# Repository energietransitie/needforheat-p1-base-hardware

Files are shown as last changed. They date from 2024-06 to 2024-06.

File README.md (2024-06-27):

# NeedForHeat P1-BASE hardware <!-- omit in toc -->

This repository contains the open hardware design files for the NeedForHeat P1-BASE device, which can be used as a [CoreInk BASE extension module](https://docs.m5stack.com/en/coreink/proto_base), on the back of an [M5Stack CoreInk](https://docs.m5stack.com/en/core/coreink) device. 

The NeedForHeat P1-BASE enables reading [smart meters that adhere to the Dutch Smart Meter Requirements](https://github.com/energietransitie/dsmr-info) via the [P1 port](https://nl.wikipedia.org/wiki/P1-poort).

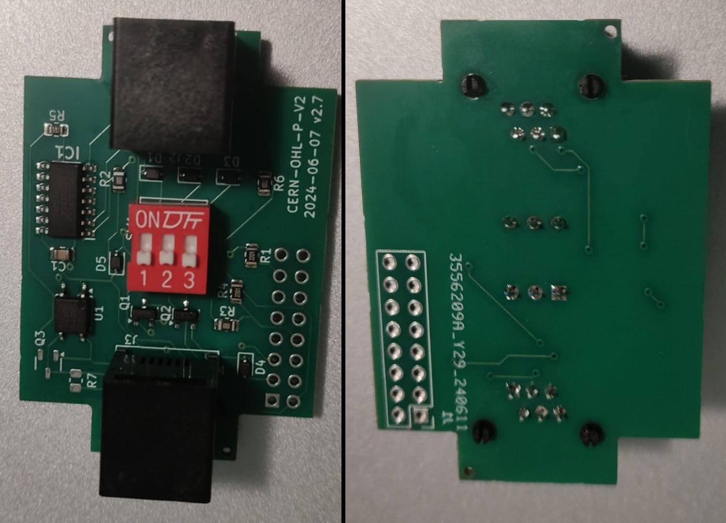
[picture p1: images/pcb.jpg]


## Table of contents <!-- omit in toc -->
- [General info](#general-info)
- [Producing](#producing)
  - [Printed Circuit Board](#printed-circuit-board)
  - [Enclosure](#enclosure)
- [Deploying](#deploying)
  - [Cost](#cost)
  - [Connecting](#connecting)
  - [Setting the DIP Switches](#setting-the-dip-switches)
- [Developing](#developing)
  - [Printed Circuit Board](#printed-circuit-board-1)
- [Features](#features)
- [Status](#status)
- [License](#license)
- [Credits](#credits)

## General info
This repository contains the open hardware designs files for the NeedForHeat P1-BASE. It also includes a `docs` folder with recent printouts of the [schematics](./docs/needforheat-p1-base-hardware-sch.pdf) and [PCB layout](./docs/needforheat-p1-base-hardware-pcb.pdf). 

For the associated firmware that you can run on this device, please see [this repository](https://github.com/energietransitie/needforheat-p1-reader-firmware).

## Producing

### Printed Circuit Board
To manufacture the printed circuit board you can use various PCB services. 

The folder [pcb/jlcpcb](./pcb/jlcpcb) includes all exported files needed to have the PCBs manufactured by [JLCPCB](https://www.jlcpcb.com). Upload the [zipped gerber files](./pcb/jlcpcb/assembly/GERBER-needforheat-p1-base-hardware.zip) to the [JLCPCB quote page](https://cart.jlcpcb.com/quote), select the amount of PCBs and a colour for the silkscreen. All other options can be left on default. 

If you do not want to solder components on the PCB yourself, select `PCB assembly` and JLCPCB will do it for you (even for through-hole components if you so desire). This will take you to a page where the BOM and POS file can be uploaded. Use the files [BOM-needforheat-p1-base-hardware.csv](./pcb/jlcpcb/assembly/BOM-needforheat-p1-base-hardware.csv) and [CPL-needforheat-p1-base-hardware.csv](./pcb/jlcpcb/assembly/CPL-needforheat-p1-base-hardware.csv).

JLCPCB provides detailed steps on their website to select component assembly, including wave soldering. For wave soldering or through-hole component assembly, specify this requirement when uploading your BOM and POS files. 

> After uploading BOM and CPL, you may be asked to select a component for `Q3`. You do not need to do so and can select 'do not place'. For more information, see the [design document](docs/documentation.md#optional-components).

### Enclosure

An enclosure for this device has not been developed yet.

<!-- an enclosure has not been developed yet
To fabricate the enclosure you can use your own 3D printer or use a 3D printing service. 

<img src="./images/enclosure.jpg" height="600" />

The folder [enclosure/fabrication](./enclosure/fabrication) contains exported STL files for the [case](./enclosure/fabrication/twomes-hardware-repository-template-case.stl) and [lid](./enclosure/twomes-hardware-repository-template-lid.step) of the NeedForHeat P1-BASE enclosure. The STL files can be imported into any slicer and turned into G-Code for a 3D printer.
-->

## Deploying

To deploy P1-BASE to a home as the NeedForHeat Smart Meter module, in addition to the PCB you need additional hardware: enclusure, M5Stack CoreInk, a short RJ12 cable and for some homes a power adapter. In this section we describe the cose and connections.

### Cost

Prices indicate price per module in June 2024, based on ordering enough hardware for 10 modules, including 21% VAT and shipping to an address in the Netherlands.

| # | Item | Supplier | Price per Unit | Subtotal |  Shipping | Total |
| --- | --- | --- | ---: | ---: | ---: | ---: |
| 1 | P1-BASE PCB | JLCPCB | €2.40 | €2.40 | €2.38 | €4.78 |
| 1 | P1-BASE enclosure | JLCPCB | €1,30 | €1,30 | €2,40 | €3,60 |
| 1 | [M5Stack CoreInk](https://www.tinytronics.nl/nl/platformen-en-systemen/m5stack/e-paper/m5stack-m5core-ink-met-1.54-inch-e-paper-e-ink-display-esp32) | TinyTronics | €43.00 | €43.00 | €0.00 | €43.00 |
| 4 | [LEGO pen stroef + pen stroef](https://www.blokjeskoning.nl/product/pen-stroef-pen-stroef-zwart/) | Blokjeskoning | €0.03 | €0.12 | €0.30 | €0.42 |
| 1 | [RJ12 cable (male-male; 6P6C; straight; 0.5 m or shorter)](https://www.amazon.nl/-/en/InLine-18848A-Modular-Cable-6-Core/dp/B005I1UDOE/)[^1] | AlleKabels  | €5.95 | €5.95 | €0.00 | €5.95 |
| 1 | [USB-A 230V charger + USB-A to USB-C cable](https://www.allekabels.nl/usb-oplader/4508/3636716/usb-a-oplader-usb-c-kabel.html) | AlleKabels  | €14.95 | €14.95 | €0.13 | €15.08 |
| | **TOTAL** | | **€67.60** | **€67.72** | **€6,21** | **€72,83** |

[^1]: The shorter the cable the better: this allows users to simply click in the RJ12 connector of te to the P1 port of their smart to leave and leave the NeedForHeat smart meter reader device dangling from the P1-port;*

### Connecting

Assuming that the PCB is fully assembled, the device has an enclosure, and the device has been programmed with the [needforheat-p1-reader-firmware](https://github.com/energietransitie/needforheat-p1-reader-firmware), you can proceed and connect the device as follows:

Before sending the device to a home:

1. Mount the P1-BASE in its enclosure.
1. Connect the short RJ12 cable to the upper female RJ12 connector[^2].
1. Insert 2 lego pens in the enclusure at opposite diagonal corners. 
1. Insert 2 lego pens in the holes on the back side of the M5Stack CoreInk at opposite diagonal corners.
4. Do NOT connect the P1_BASE and M5Stack CoreInk, before sending, since they will not fit in a standard [PostNL brievenbusdoos](https://shop.postnl.nl/webshop/verpakkingen/brievenbusdoos-a5-255x160x28mm) when stacked.

[^2]: By pre-connecting the RJ12 cable to connector `J2` on the PCB, you help users at home avoid installation errors. You may even consider clipping off 3 to 4 mm from the latch of the modular conector. After insertion the connector does not protrude from the female connecto, which clearly signals to the user that this cable should not be deinstalled. 

After receiving the device in a home:
1. Connect to the P1-BASE to the based of the M5Stack CoreInk, ensuring alignment of M5Stack CoreInk with the P1-BASE; the LEGO pins will help make sure that the 2x8 pin connector of the P1-BASE properly connects to M5Stack CoreInk.
2. Unplug your existing smart meter reader (if any) from the P1 port smart meter
3. Connect the plug of the NeedForHeat smart meter module in the P1 port .
4. Plug the RJ16 connector of our existing smart meter reader into the bottom RJ12 socket of the P1-BASE.

### Setting the DIP Switches

The hardware version v2.7 (2024-06-07) features 3 DIP switches on the PCB to control data request line management. Adjust the switches according to the following settings before delivering the device to the user:

| DIP-switch Number | ON Position | OFF Position |
| --- | --- | --- |
| 1 | Data requested continuously (DSMR 4 & 5) | Data not requested continuously |
| 2 | Data request driven by M5Stack CoreInk | Data request from M5Stack CoreInk ignored |
| 3 | Data request driven by external smart meter reader | Data request from external smart meter reader ignored |

If multiple DIP switches are ON simultaneously, data is requested if any corresponding source requires it. This may cause the external smart meter reader to receive partial messages, but according to the [DSMR P1 Port Companion Standard](https://github.com/energietransitie/dsmr-info?tab=readme-ov-file#dsmr-versions-standards) since version 3.0, smart meter readers should be able to handle partial messages.

## Developing

### Printed Circuit Board
To change the hardware design of the PCB, you need:
* [KiCad version 8.0.0 or later](https://www.kicad.org/download/) installed to change te PCB design. 

The KiCad source files of the PCB can be found in the folder [pcb](./pcb).

To convert the PCBs into a format suitable for fabrication, consult the webpage of your PCB manufacturer of choice. For example, see the [JLCPCB guide on how to export Gerbers](https://support.jlcpcb.com/article/149-how-to-generate-gerber-and-drill-files-in-kicad) and the  [JLCPCB guide how to export the BOM and POS files](https://support.jlcpcb.com/article/84-how-to-generate-the-bom-and-centroid-file-from-kicad). You may also use a KiCad plug-in for this purpose such as [kicad-jlcpcb-tools](https://github.com/Bouni/kicad-jlcpcb-tools).

<!-- 
### Enclosure
To change the hardware design of the enclosure, you need either:
* [Autodesk Fusion 360](https://www.kicad.org/download/) installed (Autodesk provides 30 day free trials and [free one-year educational access](https://www.autodesk.com/education/edu-software/overview?sorting=featured&filters=individual) to its products and services for eligible students, teachers and research staff); 
* or [FreeCAD](https://www.freecadweb.org/), an open source alternative.

The source files of the enclosure can be found in the folder [enclosure](./enclosure). We include both .f3d source files and .step source files we obtained after conversion.
-->

## Features

The NeedForHeat P1-BASE includes the following main hardware components:

- [x] Built-in P1-splitter for connecting an additional smart meter reader to the lower female RJ12 connector (`J3`).
- [x] Integrated [Schmitt trigger](https://en.wikipedia.org/wiki/Schmitt_trigger) to reduce signal noise.
- [x] 3 DIP-switches on the PCB for enabling/disabling data request line management.
- [x] Bottom-side 2x8 pin header for MI-BUS connection to the [M5Stack CoreInk](https://docs.m5stack.com/en/core/coreink) (requires soldering yourself, or a hefty JLCPCB fee for bottom-side hand-soldering).

To-do:

- [ ] Test compatibility with Landis+Gyr E360 series smart meters (e.g., [Landis+Gyr CD2D](https://www.landisgyr.eu/), [CM3D](https://www.landisgyr.eu/)).
- [ ] Consider using 'upside-down' RJ12 female connectors for easier [M5Stack CoreInk](https://docs.m5stack.com/en/core/coreink) screen readability.
- [ ] Evaluate relocating and optimizing the 2x8 pin header from the bottom side to the top side of the PCB to reduce manufacturing costs. 
  > (This would also obviate the need for 'upside-down' RJ12 female connectors, above.)
- [ ] Refine PCB design to reduce clutter where possible.
- [ ] Experiment with alternative data request management methods (e.g., MOSFETs, BJTs), which would allow the [M5Stack CoreInk](https://docs.m5stack.com/en/core/coreink) to check and control data request management in software.
- [ ] Implement low-power LEDs for indicating power status, data request status, and data flow.
- [ ] Develop energy-efficient charging strategies for the [M5Stack CoreInk](https://docs.m5stack.com/en/core/coreink) 390 mAh LiPo battery from DSMR 4 and DSMR 5 smart meters, without triggering the fold-back current limiting feature of some smart meters.
- [ ] Design a 3D-printable enclosure compatible with the [M5Stack CoreInk](https://docs.m5stack.com/en/core/coreink), potentially using [LEGO connector pens](https://www.blokjeskoning.nl/product/pen-stroef-pen-stroef-zwart/). A preliminary version can be found in the [needforheat-boiler-monitor-hardware repository](https://github.com/energietransitie/needforheat-boiler-monitor-hardware).

## Status
Project is:  _in progress_

## License
The hardware designs in this repository are available under the [CERN-OHL-P v2 license](./LICENSE), Copyright 2024 [Research group Energy Transition, Windesheim University of Applied Sciences](https://windesheim.nl/energietransitie)

## Credits
This open hardware design is a collaborative effort of:
* Rick de Graaf · [@277r](https://github.com/277r) 
* Gerwin ten Have · [@GerwintenHave](https://github.com/GerwintenHave) 

Product owners:
* Henri ter Hofte · [@henriterhofte](https://github.com/henriterhofte) · Twitter [@HeNRGi](https://twitter.com/HeNRGi)
* Marco Winkelman · [@MarcoW71](https://github.com/MarcoW71)

We use and gratefully acknowlegde the efforts of the makers of:
* [Twomes P1 Gateway Hardware](https://github.com/energietransitie/twomes-p1-gateway-hardware), by Research group Energy Transition at Windesheim University of Applied Sciences, licenced under Apache 2.0
* [KiCad Libraries](https://kicad.github.io/), by the KiCad Development Team, licensed under [an adapted version of the CC-BY-SA 4.0 License](https://www.kicad.org/libraries/license/)

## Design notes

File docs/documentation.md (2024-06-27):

# P1-BASE-hardware Documentation <!-- omit in toc -->

## Table of contents <!-- omit in toc -->
- [Usage](#usage)
- [Design choices](#design-choices)
  - [Smart meter connection](#smart-meter-connection)
  - [Data Request Line Management](#data-request-line-management)
  - [Internal Splitter](#internal-splitter)
  - [Optional components](#optional-components)

## Usage


> This guide assumes that the PCB's are fully assembled, that the device has an enclosure and that the device has been programmed with the [needforheat-p1-reader-firmware](https://github.com/energietransitie/needforheat-p1-reader-firmware) 

* The 2x8 male pin header (`J1`) soldered to the bottom side of the PCB should be connected to the M5Stack CoreInk. Of the two possible orientations, use the  one with the best alignment of the outline of the P1-BASE PCB with the outline M5Stack CoreInk. 
* The upper female RJ12 connector (`J2`) should be connector via a (preferably short) 6P6C male-to make stright RJ12 cable to the P1 port of the smart meter. 
* The lower female RJ12 connector (`J3`) allows another smart meter reading device to be connected via a straight RJ12 cable.

Once these connections have been made, the user can open the NeedForHeat application on their phone and scan a QR code from the E-Ink screen of the M5Stack CoreInk. 

## Design choices

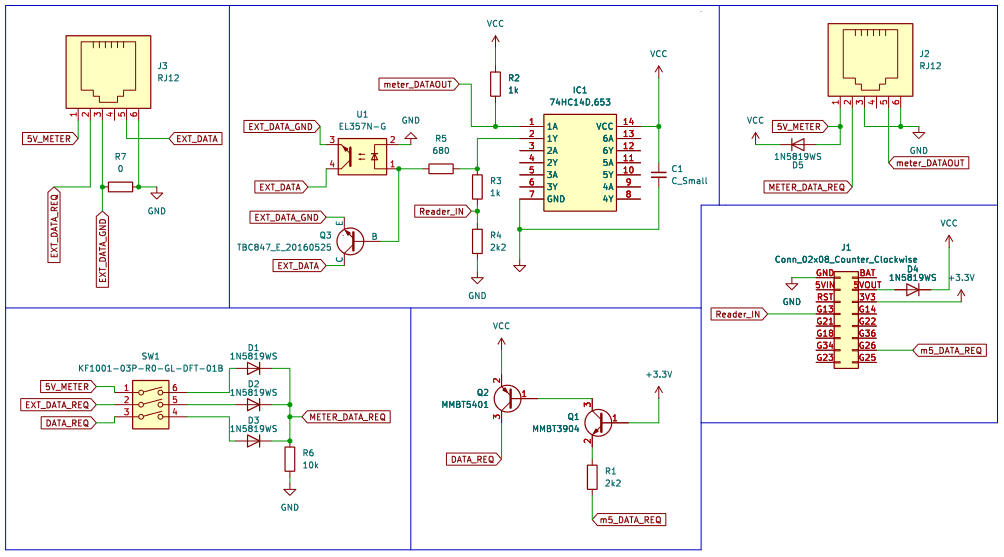
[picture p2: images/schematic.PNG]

The P1-BASE-hardware design was made as an improvement to the [twomes-p1-gateway-hardware](https://github.com/energietransitie/twomes-p1-gateway-hardware): 
* The hardware was developed to work on the M5Stack CoreInk instead of a bare ESP32.
* The [twomes-p1-gateway-hardware](https://github.com/energietransitie/twomes-p1-gateway-hardware) did not read P1 signals reliably from Landis+Gyr E360 series smart meters, such as the Landis+Gyr CD2D (meter code E0051) and CM3D (meter codes E0052 and E0067). The hardware design was also changed to address this problem and work on more smart meters.
* To allow  users who already have a smart meter reader connected to their smart meter, we added an internal P1 splitter to the design, which allows the user connect their smart meter reader to the bottom connector .

### Smart meter connection
The smart meter should be connected to upper female RJ12 connector (`J2`). A table of connections, referring to the official P1 port pin assignment can be seen below:

| Pin # | `J2` signal name | P1 Signal Name | P1 Description | P1 Remark |
| ----- | --- | --- | --- | --- |
| 1 | `5V_METER` | +5V | +5V power supply | Power supply line |
| 2 | `METER_DATA_REQUEST` | Data Request | Data Request Input | |
| 3 | `GND` | Data GND | Data ground | |
| 4 | | n.c. | Not connected | |
| 5 | `meter_DATAOUT` | Data | Data line | Output, Open collector |
| 6 | `GND` | Power GND | Power ground | Power supply line |

### Data Request Line Management
When the `Data Request` voltage (pin 2 on the female RJ12 connecor of the P1 port of the smart meter) is at `Data GND`+5V, the smart meter sends data.

The [twomes-p1-gateway-hardware/](https://github.com/energietransitie/twomes-p1-gateway-hardware/) design originally utilized a 10kΩ resistor and a 3.3V source, resulting in a high RC time constant and unreliable data reading. To address this, the design has been revised with a 1kΩ resistor and a 5V source, allowing for 5mA current flow and significantly improving signal integrity. The `meter_DATAOUT` signal is connected to a Schmitt-trigger (`IC1`) to enhance noise immunity. Transistors `Q1` and `Q2` are configured in a level-shifter circuit, converting the 3.3V logic signal (`m5_DATAREQ`) arriving from the M5Stack CoreInk via `G26` to a 5V logic signal (`DATA_REQ`), which is expected as `Data Request` input by the smart meter's P1-port.

### Internal Splitter

The internal splitter eliminates the need for external pre-wired components, simplifying user connections. It facilitates the addition of another smart meter reader without affecting the primary device's data request capabilities. Diodes are incorporated to prevent current flow to `GND` and ensure uninterrupted data request functionality. 

A DIP switch (`SW1`) enables configuration of `5V_METER`, `EXT_DATA_REQ`, and `DATA_REQ` signals to `METER_DATA_REQ`, linked via `J2` to the smart meter's data request line. For setup details, refer to the [DIP switch configuration section in the main README](../README.md#setting-the-dip-switches), which explains how these settings influence operational behavior.

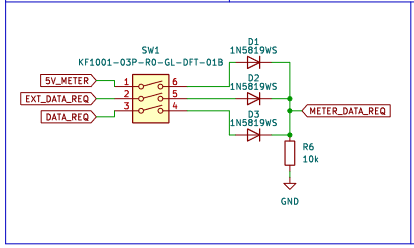
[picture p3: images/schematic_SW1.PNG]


### Optional components
* **Solder pads for `R7` and `Q3` are included on the PCB but not populated.** These components are provided for flexibility in adjusting the circuit's performance. They can be soldered if needed to enhance signal readout quality, particularly if the optocoupler (`U1`) proves insufficiently fast for the signals.

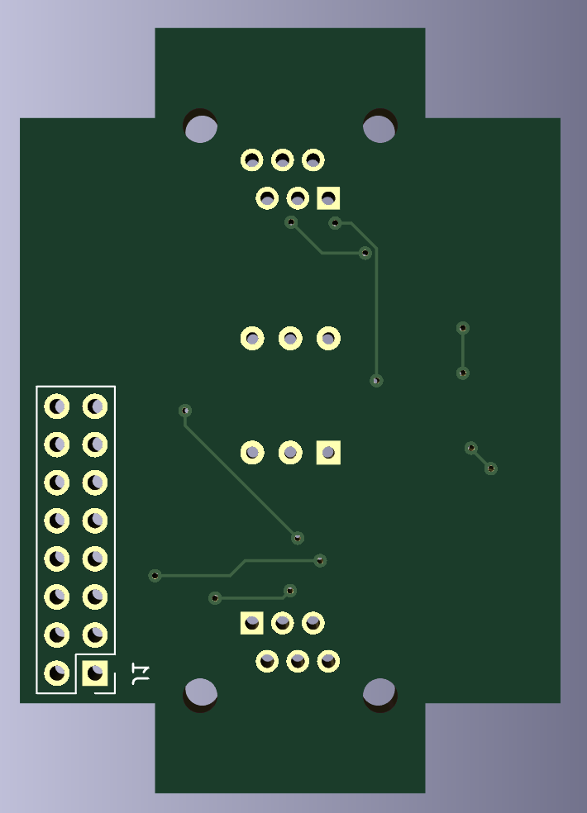
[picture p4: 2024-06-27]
images/needforheat-p1-base-hardware-bottom.PNG

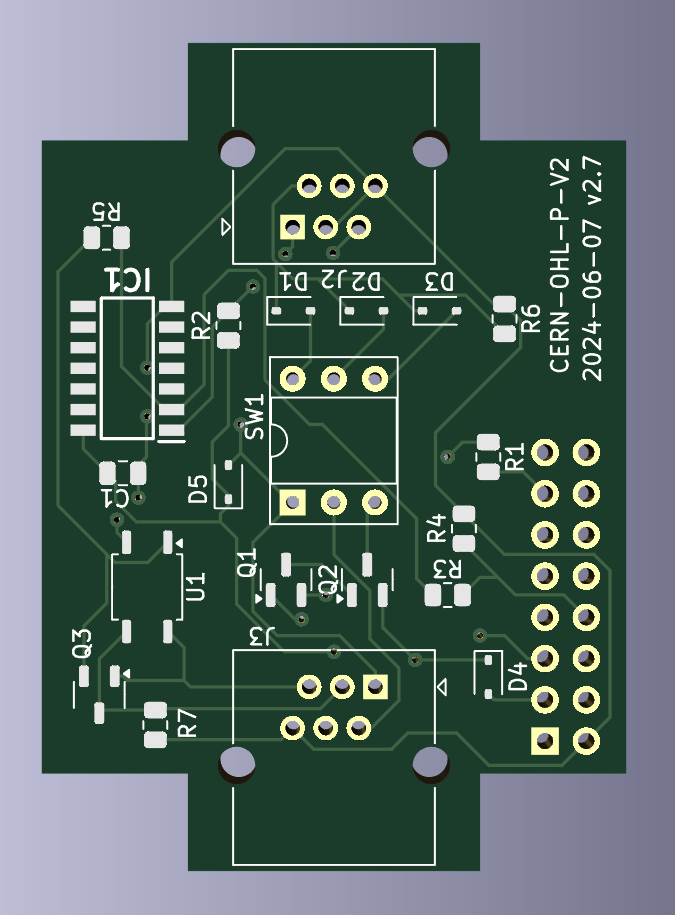
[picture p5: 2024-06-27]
images/needforheat-p1-base-hardware-top.PNG

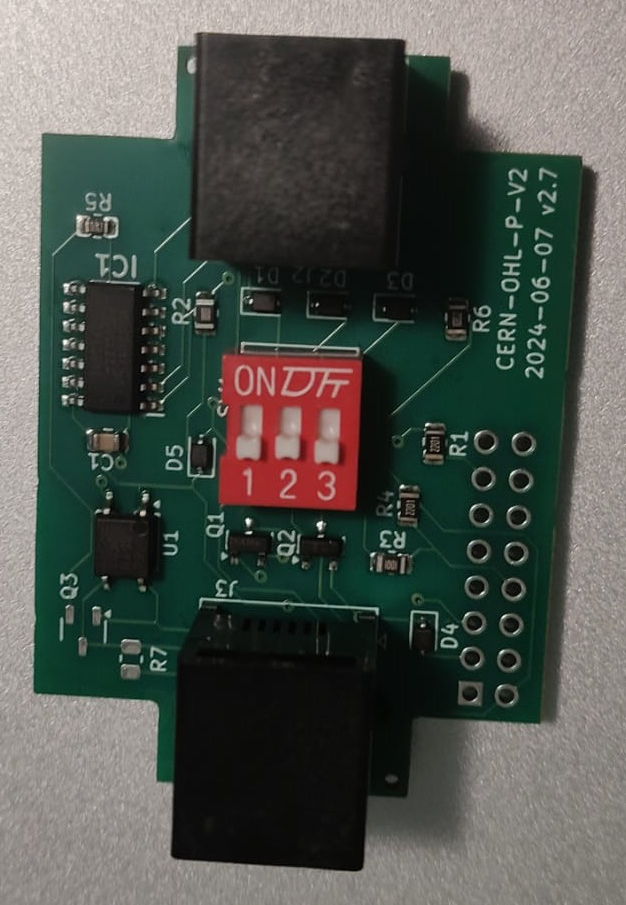
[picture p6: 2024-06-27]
images/front.jpg

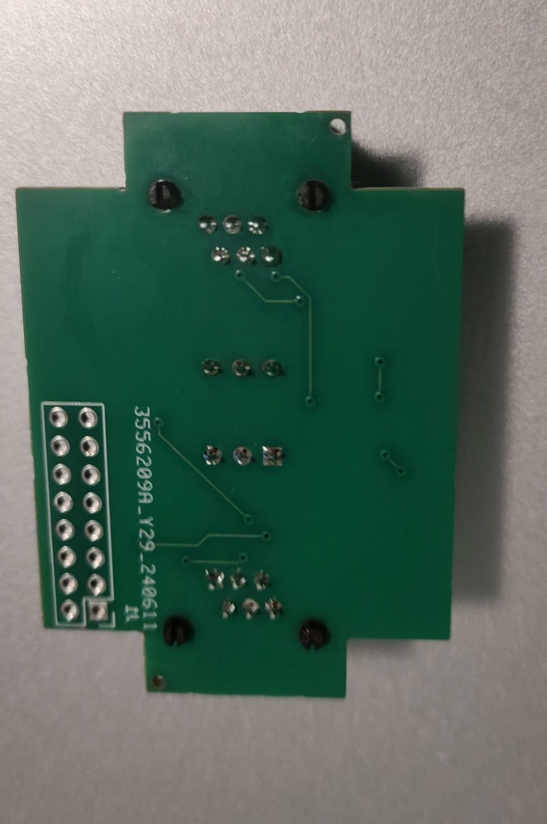
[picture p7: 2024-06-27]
images/back.jpg

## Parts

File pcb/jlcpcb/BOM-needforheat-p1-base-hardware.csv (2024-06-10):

Comment | Designator | Footprint | LCSC
10k | R6 | R_0805_2012Metric | C17414
1k | R2,R3 | R_0805_2012Metric | C17513
2k2 | R1,R4 | R_0805_2012Metric | C17520
1N5819WS | D1,D2,D3,D4,D5 | D_SOD-323 | C191023
MMBT3904 | Q1 | SOT-23 | C20526
680 | R5 | R_0805_2012Metric | C23228
EL357N-G | U1 | SOP-4_3.8x4.1mm_P2.54mm | C29981
C_Small | C1 | C_0805_2012Metric | C49678
74HC14D,653 | IC1 | SOIC127P600X175-14N | C5605
Conn_02x08_Counter_Clockwise | J1 | PinHeader_2x08_P2.54mm_Vertical | C68234
RJ12 | J2,J3 | RJ25_Wayconn_MJEA-660X1_Horizontal | C77859
MMBT5401 | Q2 | SOT-23 | C8326
KF1001-03P-R0-GL-DFT-01B | SW1 | DIP-6_W7.62mm_Socket | C976325
TBC847_E_20160525 | Q3 | SOT-23-3

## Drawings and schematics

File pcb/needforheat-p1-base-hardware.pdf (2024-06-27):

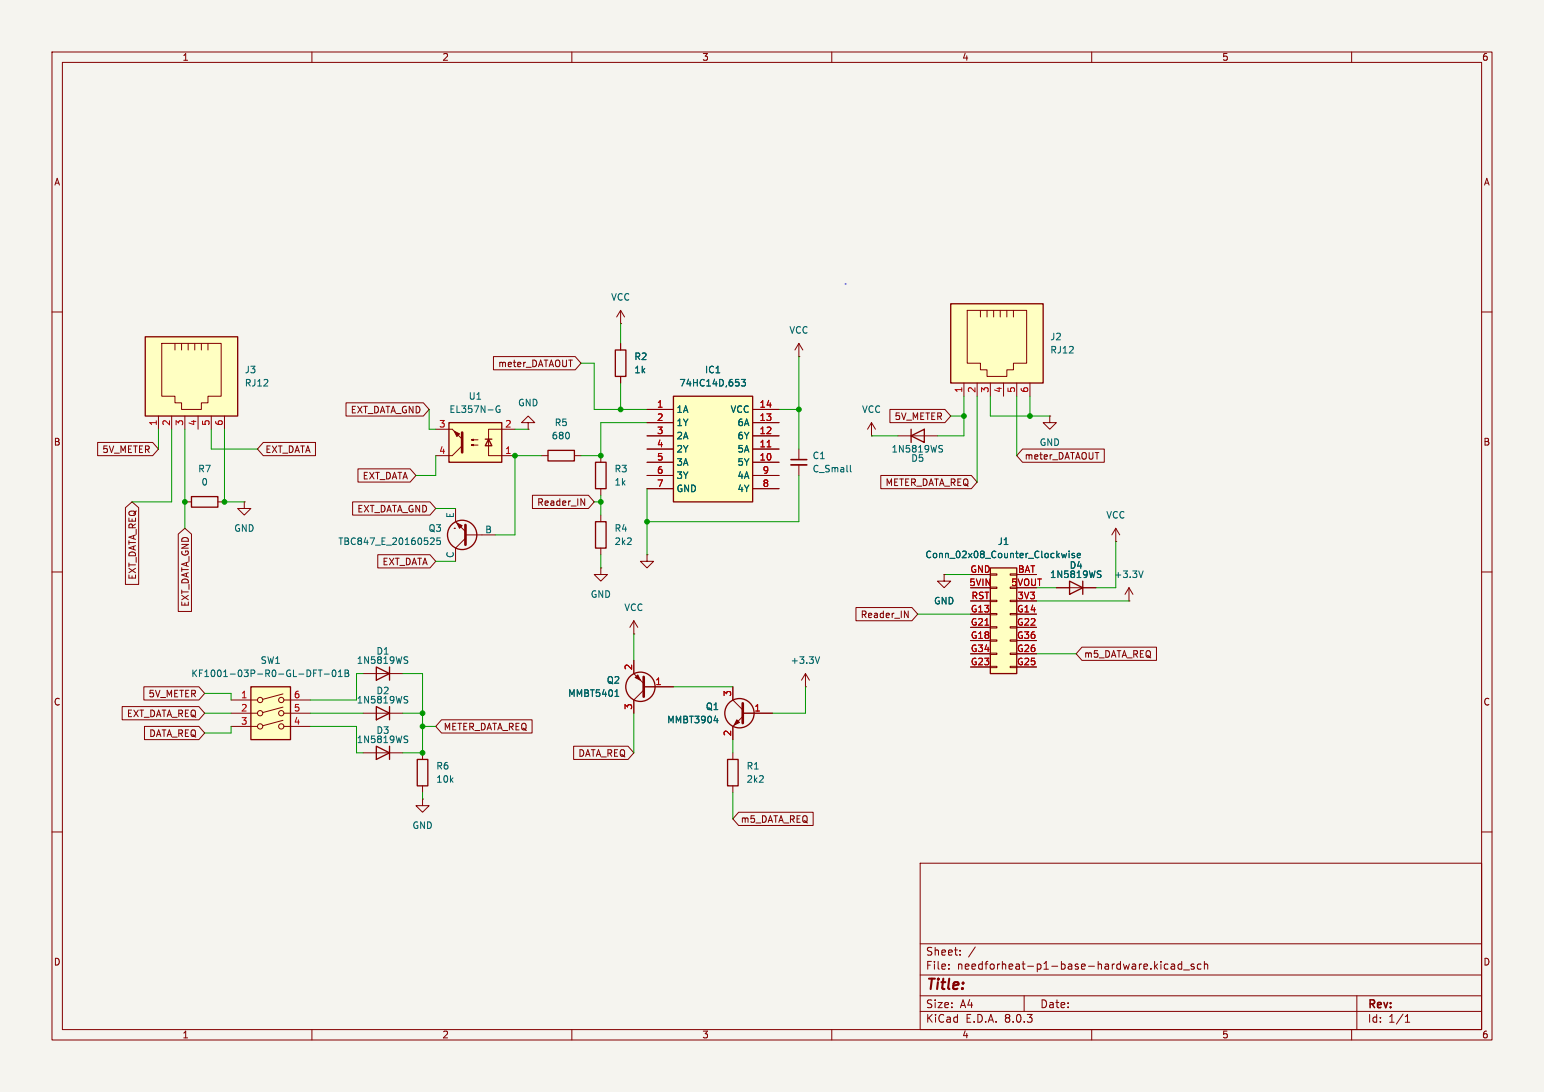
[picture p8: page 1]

Id: 1/1 Title: File: needforheat-p1-base-hardware.kicad_sch Sheet: /

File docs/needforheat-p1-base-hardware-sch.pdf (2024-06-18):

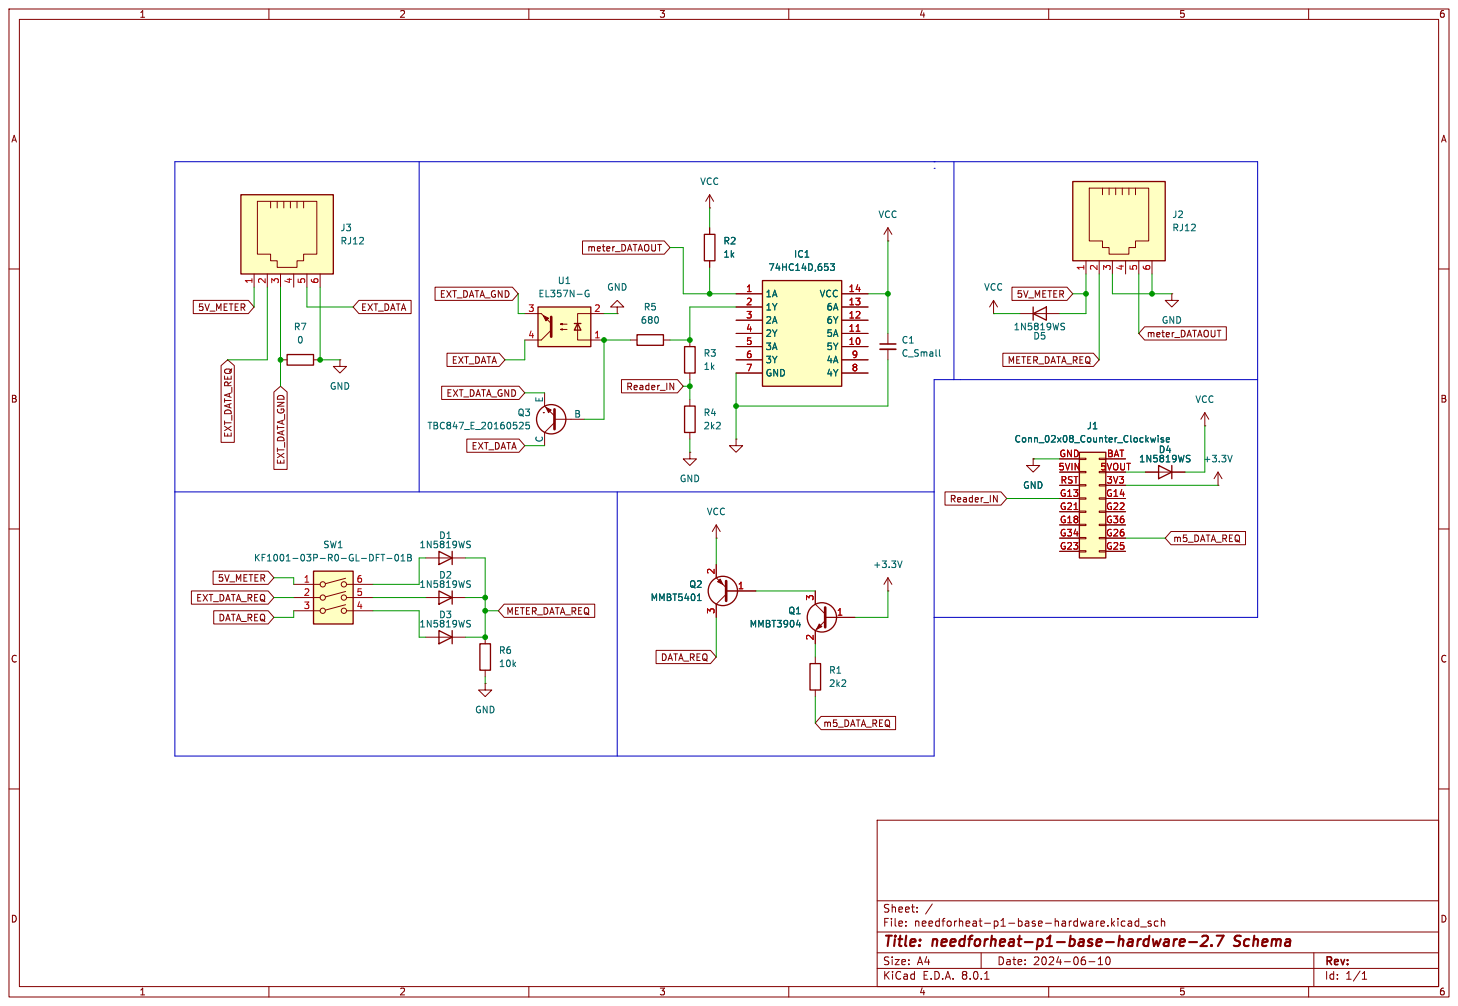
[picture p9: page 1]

File: needforheat-p1-base-hardware.kicad_sch Sheet: /

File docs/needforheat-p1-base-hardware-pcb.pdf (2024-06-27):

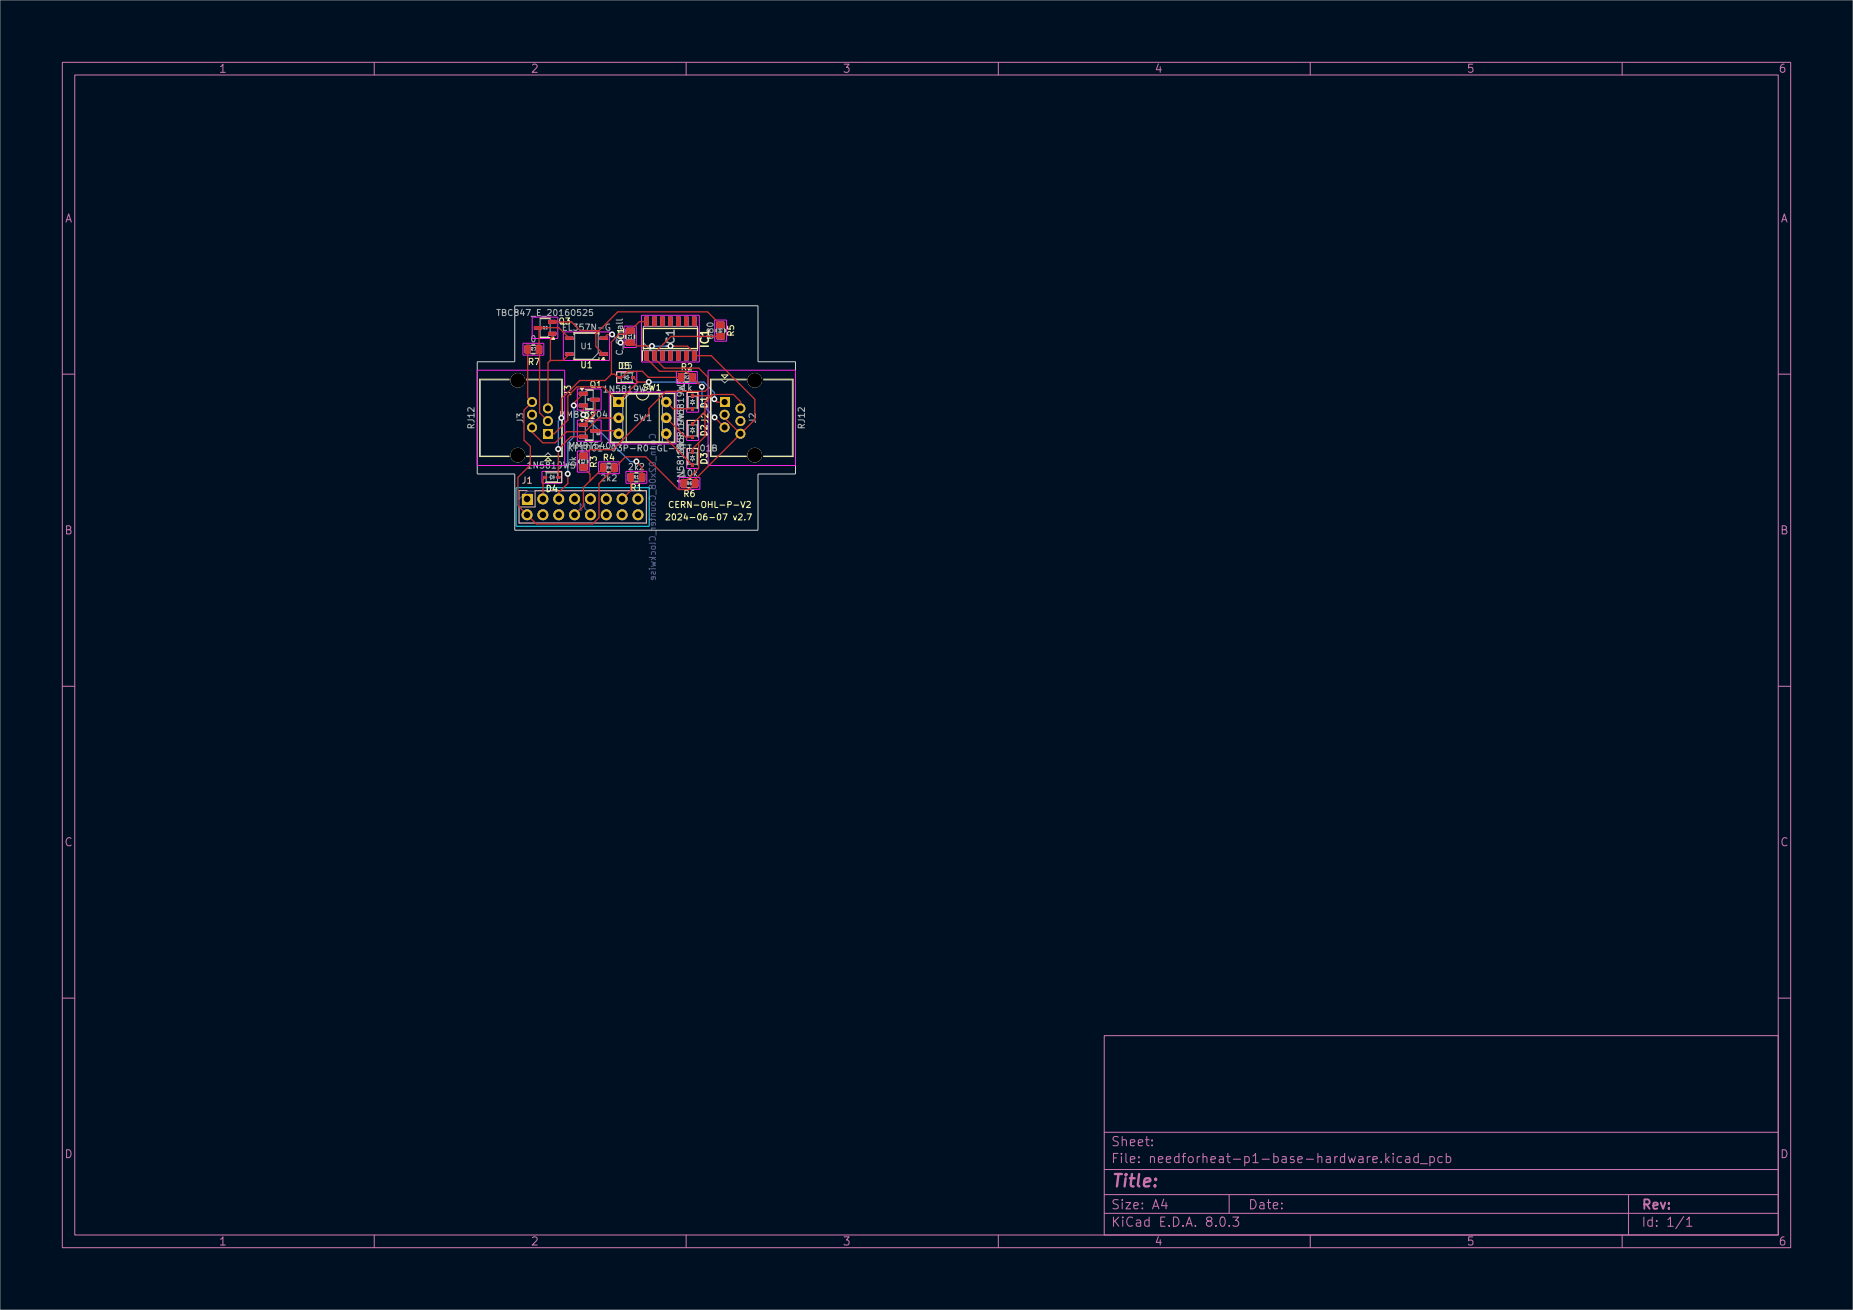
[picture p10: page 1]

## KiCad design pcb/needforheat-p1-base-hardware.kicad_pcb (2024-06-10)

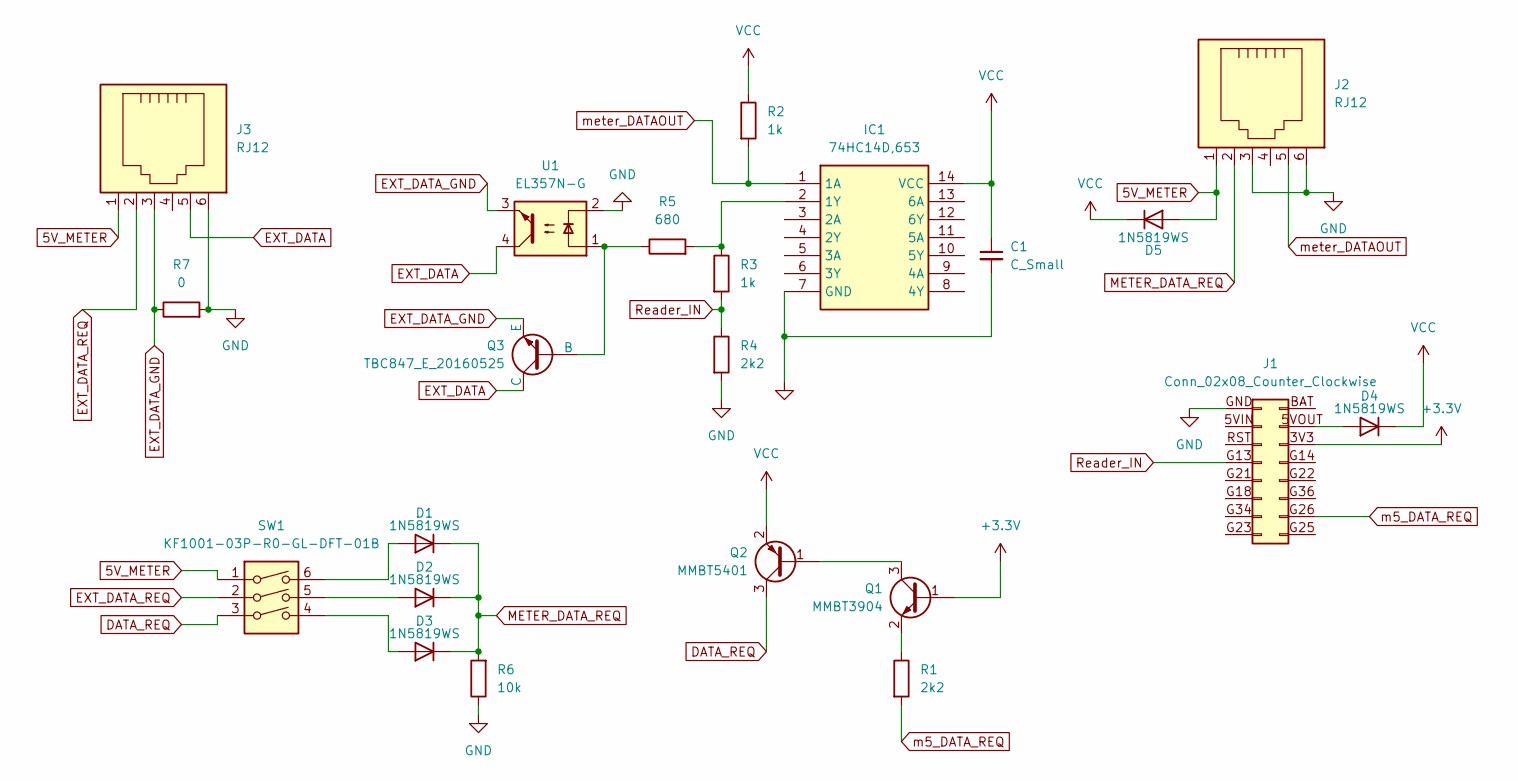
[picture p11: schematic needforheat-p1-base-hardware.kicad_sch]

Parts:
C1: C_Small; C_0805_2012Metric
D1, D2, D3, D4, D5: 1N5819WS; D_SOD-323
IC1: 74HC14D,653; SOIC127P600X175-14N; Mouser Part Number 771-74HC14D-T
J1: Conn_02x08_Counter_Clockwise; PinHeader_2x08_P2.54mm_Vertical
J2, J3: RJ12; RJ25_Wayconn_MJEA-660X1_Horizontal
Q1: MMBT3904; SOT-23
Q2: MMBT5401; SOT-23
Q3: TBC847_E_20160525; SOT-23-3
R1, R4: 2k2; R_0805_2012Metric
R2, R3: 1k; R_0805_2012Metric
R5: 680; R_0805_2012Metric
R6: 10k; R_0805_2012Metric
R7: 0; R_0805_2012Metric
SW1: KF1001-03P-R0-GL-DFT-01B; DIP-6_W7.62mm_Socket
U1: EL357N-G; SOP-4_3.8x4.1mm_P2.54mm

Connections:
5V_METER: D5.2 (A), J2.1, J3.1, SW1.1
+3.3V: J1.3V3 (Pin_14), Q1.1 (B)
DATA_REQ: Q2.3 (C), SW1.3
EXT_DATA: J3.5, Q3.1 (C), U1.4
EXT_DATA_GND: J3.3, Q3.3 (E), R7.1, U1.3
EXT_DATA_REQ: J3.2, SW1.2
GND: C1.2, IC1.7 (GND), J1.GND (Pin_1), J2.3, J2.6, J3.6, R4.2, R6.1, R7.2, U1.2
METER_DATA_REQ: D1.1 (K), D2.1 (K), D3.1 (K), J2.2, R6.2
unnamed: D1.2 (A), SW1.6
unnamed: D2.2 (A), SW1.5
unnamed: D3.2 (A), SW1.4
unnamed: D4.2 (A), J1.5VOUT (Pin_15)
unnamed: IC1.2 (1Y), R3.1, R5.2
unnamed: Q1.3 (C), Q2.1 (B)
unnamed: Q1.2 (E), R1.1
unnamed: Q3.2 (B), R5.1, U1.1
Reader_IN: J1.G13 (Pin_4), R3.2, R4.1
VCC: C1.1, D4.1 (K), D5.1 (K), IC1.14 (VCC), Q2.2 (E), R2.1
m5_DATA_REQ: J1.G26 (Pin_10), R1.2
meter_DATAOUT: IC1.1 (1A), J2.5, R2.2

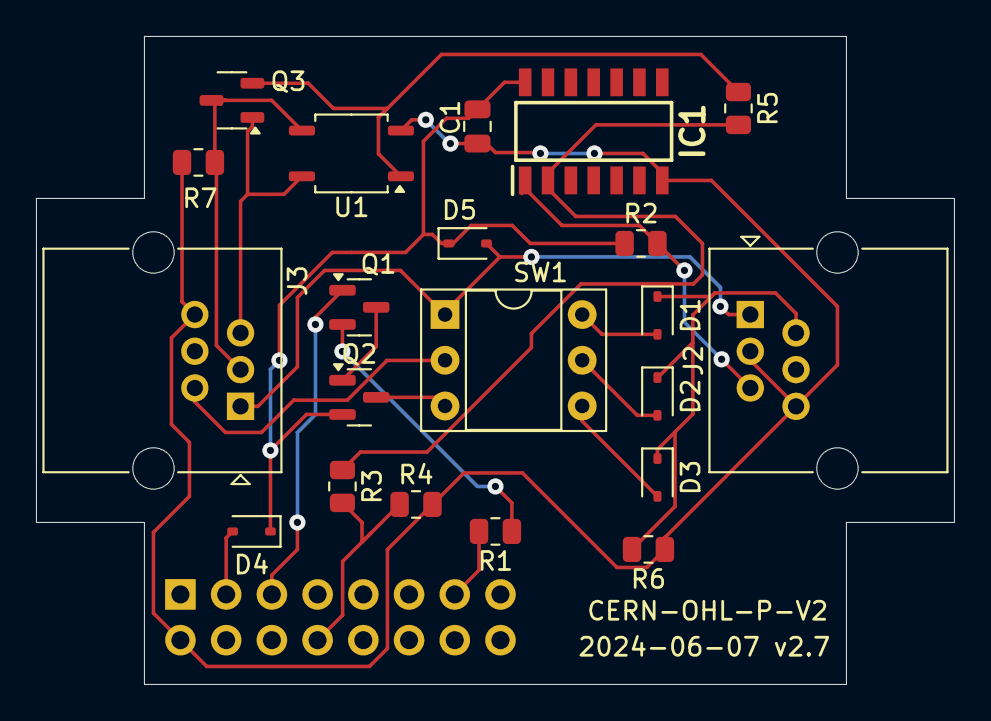
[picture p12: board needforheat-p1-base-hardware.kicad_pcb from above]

Board: 2 copper layers, 51.0 x 36.0 mm, 22 parts (1 on the bottom side), 20 nets.

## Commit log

2024-05-29 Added KiCAD Project and JLCPCB production files
    [BOM-TwomesSomething.csv, BOM-needforheat-p1-base-hardware.csv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]
2024-06-10 updated the pcb files to p1-base v2.4
    [BOM-needforheat-p1-base-hardware.csv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]
2024-06-10 added documentation, added people to credits after receiving permission to do so, added schematic
2024-06-18 added pcb, schematic
2024-06-24 improved deployment manual, clarified descriptions, improved readability
    [twomes-hardware-repository-template-case.step, twomes-hardware-repository-template-case.stl, twomes-hardware-repository-template-enclosure.f3d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]
2024-06-24 acknowledge KiCad Libraries
2024-06-26 reorganized jlcpcb file locations and added cost estimate
    [BOM-needforheat-p1-base-hardware.csv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]
